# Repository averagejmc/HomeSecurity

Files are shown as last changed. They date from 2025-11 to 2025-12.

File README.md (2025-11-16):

# HomeSecurity 

A small local home security system that:

* receives sensor data via **MQTT**
* shows a real-time dashboard using **Flask + SocketIO**
* logs hourly snapshots to a **SQLite** database
* sends notifications through **Telegram Bot API**

The app runs at **[http://localhost:5000](http://localhost:5000)**.

---

## Requirements

* Python 3.10+
* **uv** (for virtualenv + dependency management)
* Mosquitto (or any MQTT broker at `localhost:1883`)
* Telegram bot token stored in an environment variable
  `TELEGRAM_TOKEN=<your token>`

---

## Installation

### 1. Create and activate the virtual environment

```bash
uv venv
source .venv/bin/activate   # Linux/macOS
```

Windows PowerShell:

```powershell
.\.venv\Scripts\Activate.ps1
```

### 2. Install all dependencies

```bash
uv sync
```

---

## Configure Telegram

For this project, we included the bot token in the code.
However, it is recommended to use environment variables 
instead for API and bot tokens.

Set the bot token as an environment variable:

Linux/macOS:

```bash
export TELEGRAM_TOKEN="your-token"
```

Windows PowerShell:

```powershell
setx TELEGRAM_TOKEN "your-token"
```

---

## Running the App

### 1. Start the MQTT broker

```bash
mosquitto
```

### 2. Run the web server

```bash
uv run webapp.py
```

Then open:

```
http://localhost:5000
```

---

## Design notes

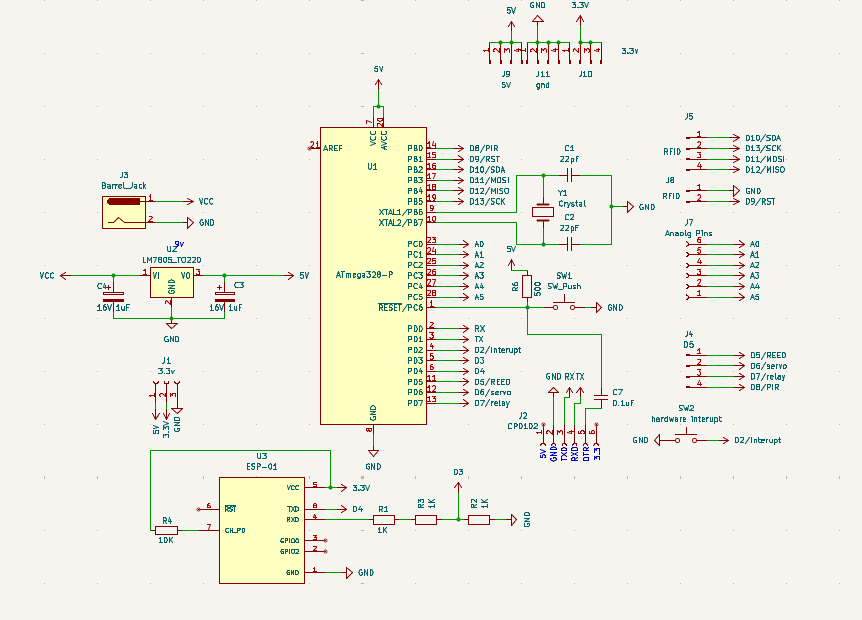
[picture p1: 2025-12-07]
schematic/schematic.png

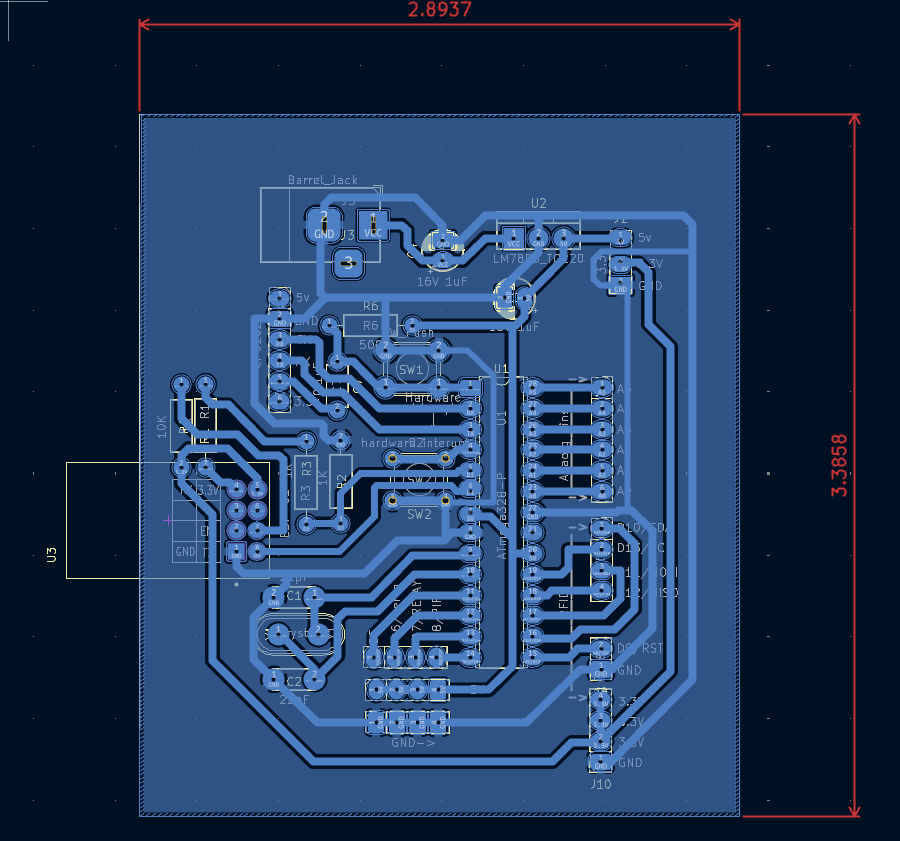
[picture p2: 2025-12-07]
schematic/routing.png

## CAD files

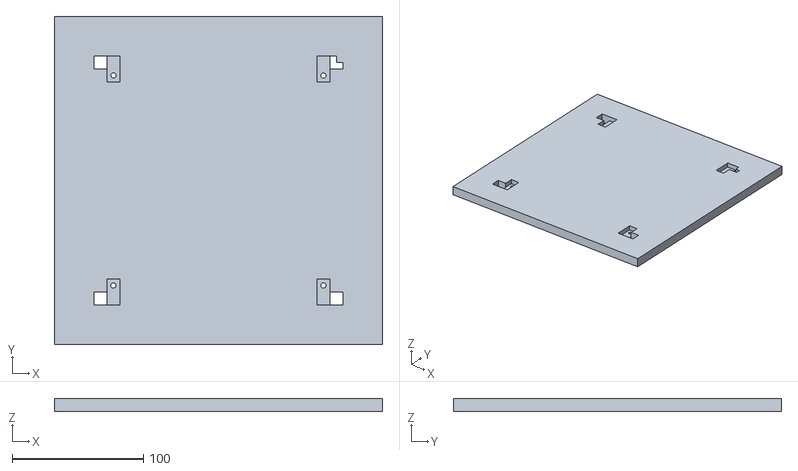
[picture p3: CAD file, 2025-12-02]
3d-models/ground.stl
250.0 x 250.0 x 10.0

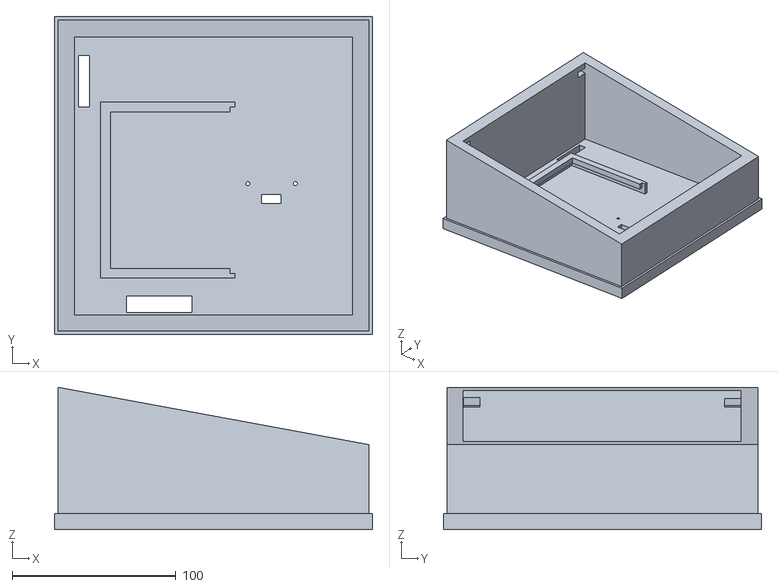
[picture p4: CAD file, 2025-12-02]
3d-models/top.stl
194.3 x 194.3 x 87.1

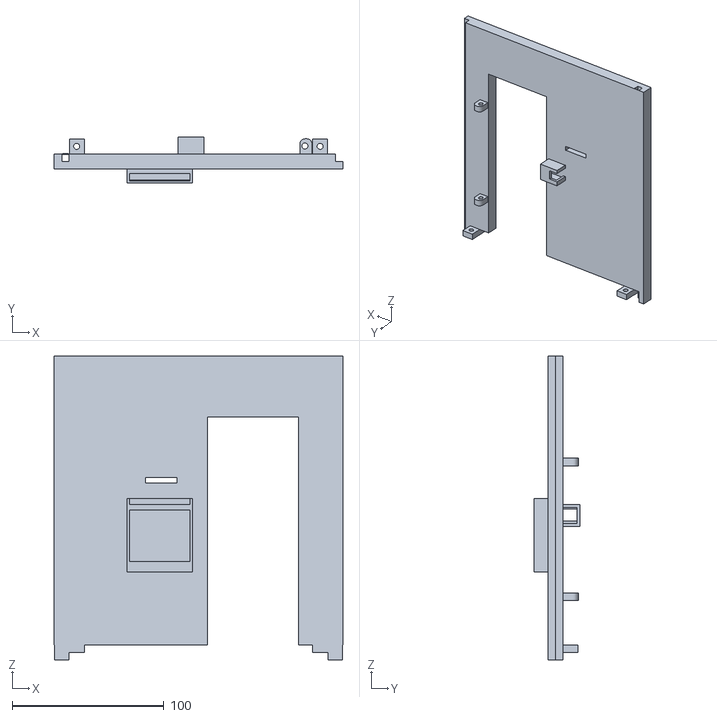
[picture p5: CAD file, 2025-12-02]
3d-models/front.stl
190.0 x 30.0 x 200.0

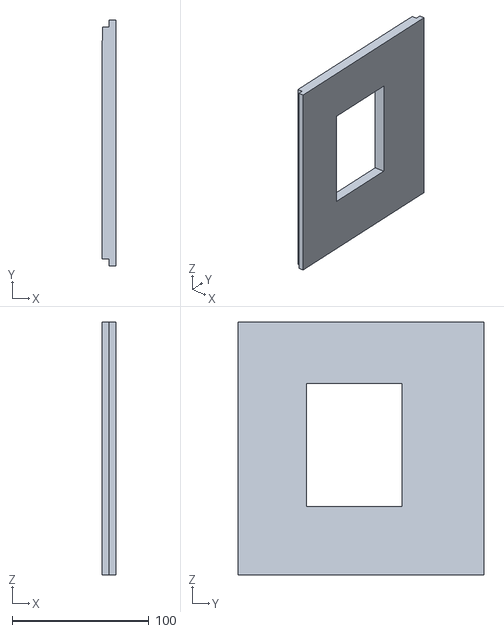
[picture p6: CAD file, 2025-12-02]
3d-models/right.stl
10.0 x 179.9 x 185.0

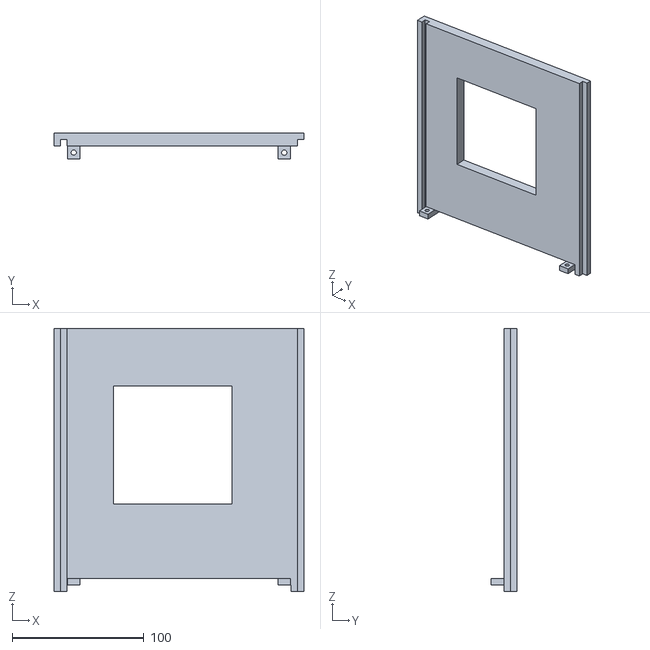
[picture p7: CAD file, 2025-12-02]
3d-models/back.stl
190.0 x 19.9 x 200.0

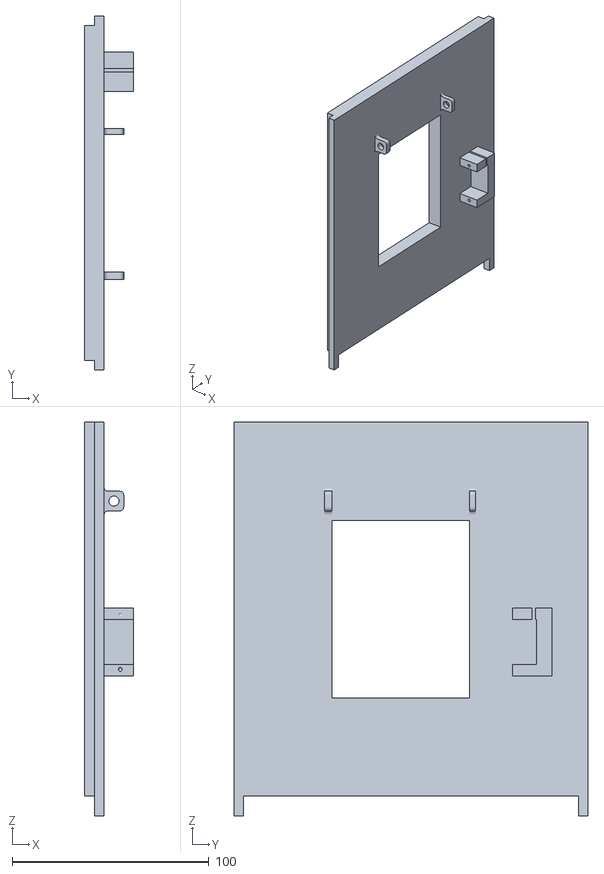
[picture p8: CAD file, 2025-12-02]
3d-models/side.stl
25.0 x 179.8 x 200.0

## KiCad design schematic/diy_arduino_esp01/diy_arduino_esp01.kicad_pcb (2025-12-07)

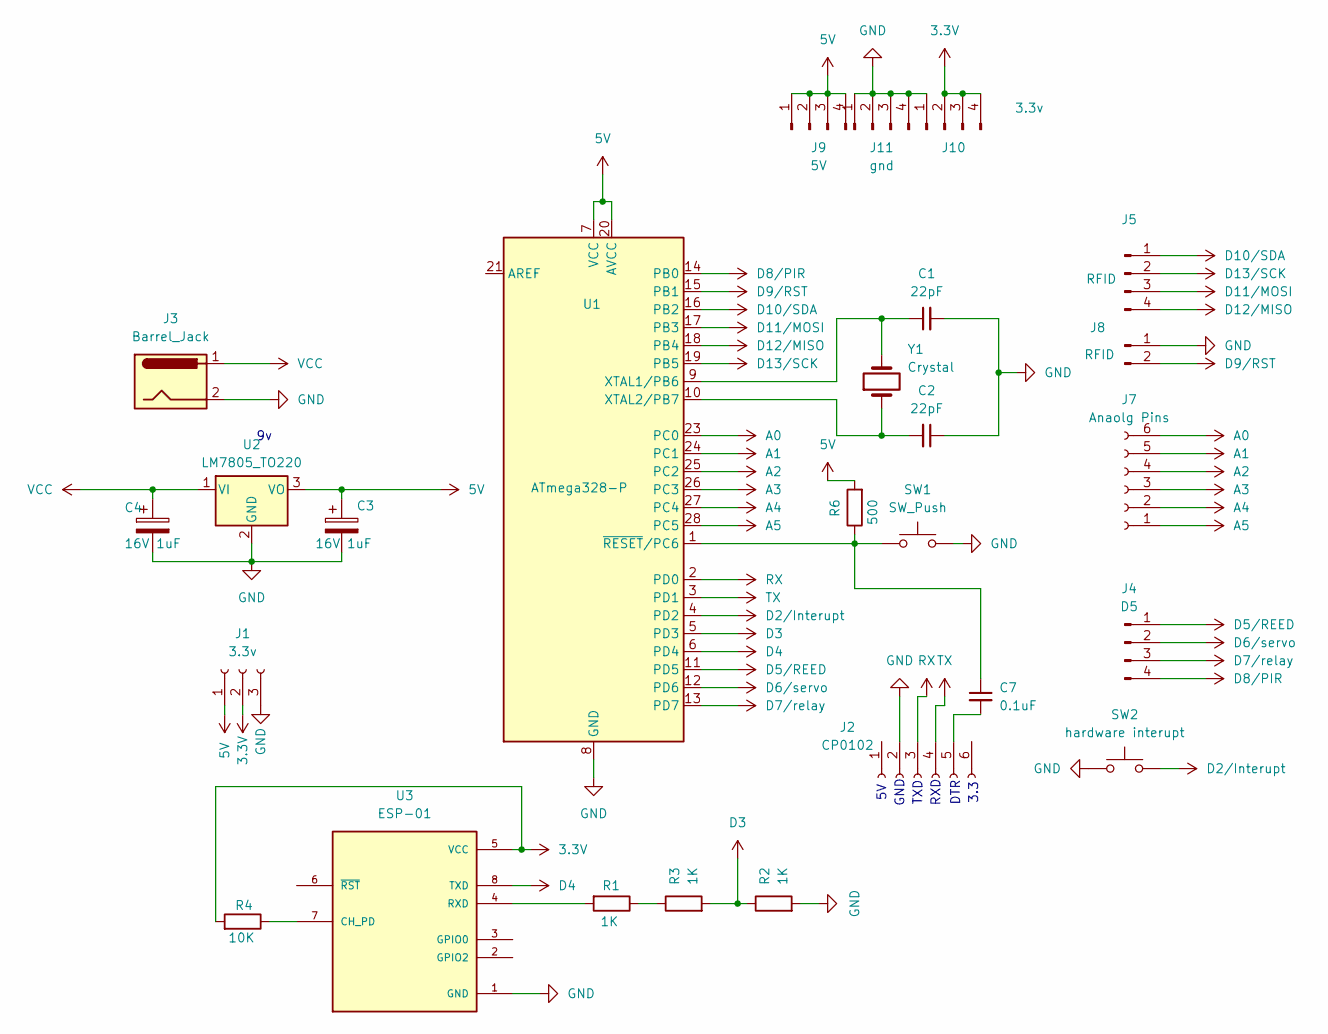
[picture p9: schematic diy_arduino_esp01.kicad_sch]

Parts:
C1, C2: 22pF; C_Disc_D5.0mm_W2.5mm_P5.00mm
C3, C4: 16V 1uF; CP_Radial_D5.0mm_P2.00mm
C7: 0.1uF; C_Disc_D5.0mm_W2.5mm_P5.00mm
J1: 3.3v; PinSocket_1x03_P2.54mm_Vertical
J2: CP0102; PinSocket_1x06_P2.54mm_Vertical
J3: Barrel_Jack; BarrelJack_Horizontal
J4: D5; PinSocket_1x04_P2.54mm_Vertical
J5: RFID; PinSocket_1x04_P2.54mm_Vertical
J7: Anaolg Pins; PinSocket_1x06_P2.54mm_Vertical
J8: RFID; PinSocket_1x02_P2.54mm_Vertical
J9: 5V; PinSocket_1x04_P2.54mm_Vertical
J10: 3.3v; PinSocket_1x04_P2.54mm_Vertical
J11: gnd; PinSocket_1x04_P2.54mm_Vertical
R1, R2, R3: 1K; R_Axial_DIN0207_L6.3mm_D2.5mm_P10.16mm_Horizontal
R4: 10K; R_Axial_DIN0207_L6.3mm_D2.5mm_P10.16mm_Horizontal
R6: 500; R_Axial_DIN0207_L6.3mm_D2.5mm_P10.16mm_Horizontal
SW1: SW_Push; SW_PUSH_6mm
SW2: hardware interupt; SW_PUSH_6mm
U1: ATmega328-P; DIP-28_W7.62mm
U2: LM7805_TO220; TO-220-3_Vertical
U3: ESP-01; MODULE_ESP-01; PARTREV 1.0
Y1: Crystal; Crystal_HC49-U_Vertical

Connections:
3.3V: J1.2, J10.2, J10.3, J10.4, R4.2, U3.5 (VCC)
5V: C3.1, J1.1, J9.1, J9.2, J9.3, J9.4, R6.2, U1.7 (VCC), U1.20 (AVCC), U2.3 (VO)
A0: J7.6, U1.23 (PC0)
A1: J7.5, U1.24 (PC1)
A2: J7.4, U1.25 (PC2)
A3: J7.3, U1.26 (PC3)
A4: J7.2, U1.27 (PC4)
A5: J7.1, U1.28 (PC5)
D2/Interupt: SW2.2, U1.4 (PD2)
D3: R2.1, R3.2, U1.5 (PD3)
D4: U1.6 (PD4), U3.8 (TXD)
D5/REED: J4.1, U1.11 (PD5)
D6/servo: J4.2, U1.12 (PD6)
D7/relay: J4.3, U1.13 (PD7)
D8/PIR: J4.4, U1.14 (PB0)
D9/RST: J8.2, U1.15 (PB1)
D10/SDA: J5.1, U1.16 (PB2)
D11/MOSI: J5.3, U1.17 (PB3)
D12/MISO: J5.4, U1.18 (PB4)
D13/SCK: J5.2, U1.19 (PB5)
GND: C1.2, C2.1, C3.2, C4.2, J1.3, J2.2, J3.2, J8.1, J10.1, J11.1, J11.2, J11.3, J11.4, R2.2, SW1.2, SW2.1, U1.8 (GND), U1.22 (GND), U2.2 (GND), U3.1 (GND)
unnamed: C7.2, J2.5
unnamed: R1.1, R3.1
unnamed: C1.1, U1.9 (XTAL1/PB6), Y1.2
unnamed: C2.2, U1.10 (XTAL2/PB7), Y1.1
unnamed: C7.1, R6.1, SW1.1, U1.1 (~RESET/PC6)
unnamed: R4.1, U3.7 (CH_PD)
unnamed: R1.2, U3.4 (RXD)
RX: J2.3, U1.2 (PD0)
TX: J2.4, U1.3 (PD1)
VCC: C4.1, J3.1, U2.1 (VI)

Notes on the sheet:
DTR
TXD
GND
RXD
3.3

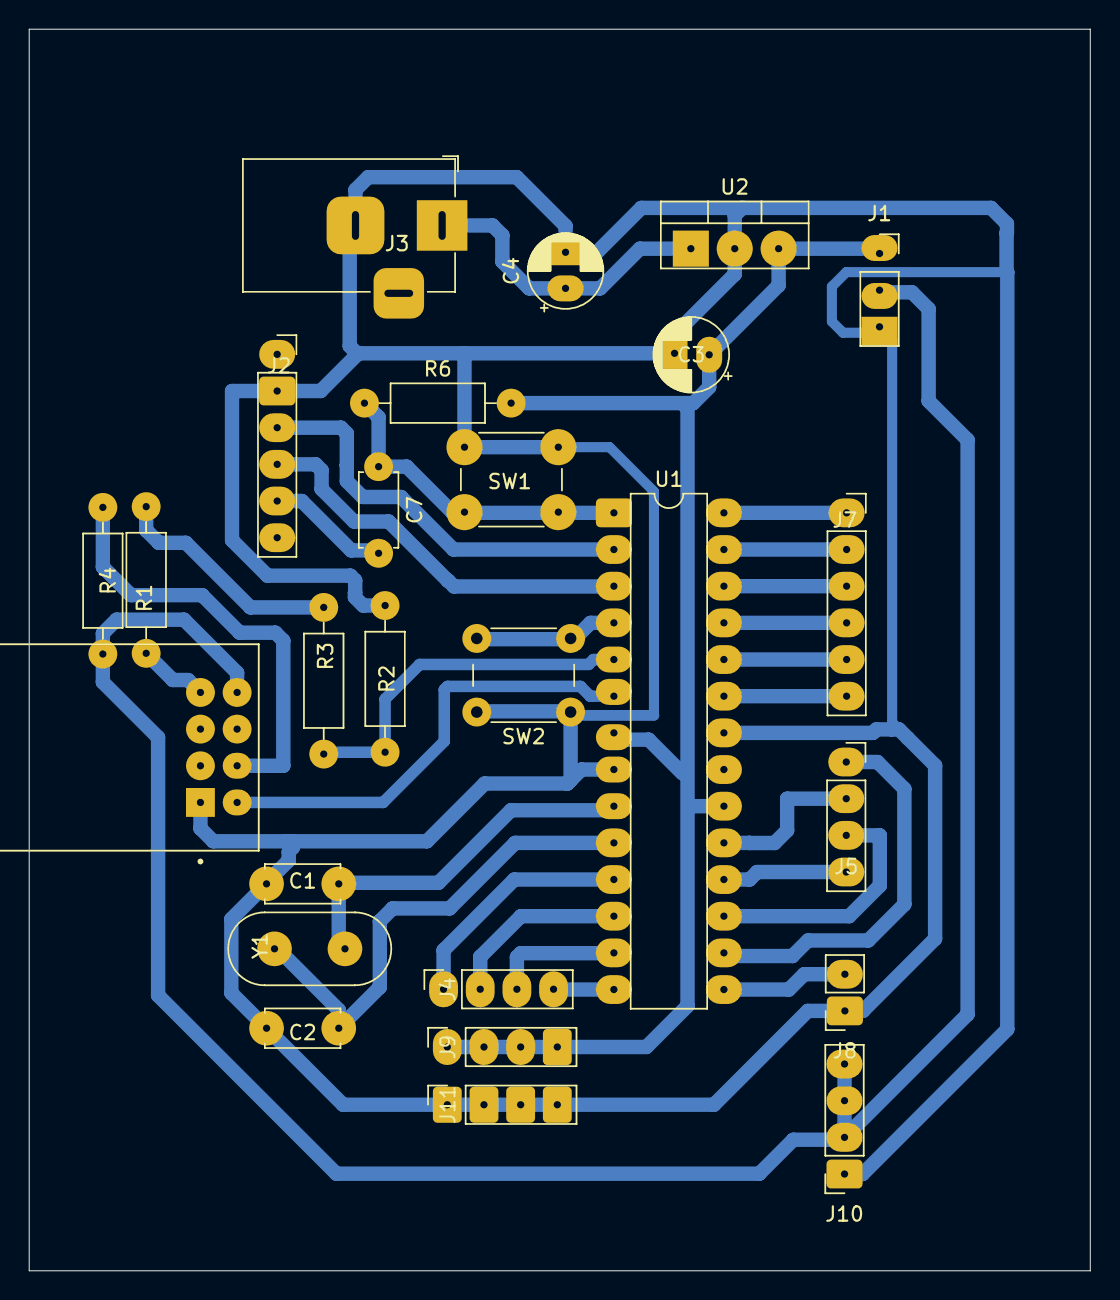
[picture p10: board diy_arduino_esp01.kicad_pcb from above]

Board: 2 copper layers, 73.5 x 86.0 mm, 26 parts (0 on the bottom side), 31 nets.

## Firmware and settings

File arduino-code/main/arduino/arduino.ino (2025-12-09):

#include <SPI.h>
#include <MFRC522.h>
#include <SoftwareSerial.h>
#include <avr/sleep.h>
#include <avr/power.h>
#include <Servo.h>

#include "DoorSensor.h"
#include "MotionSensor.h"
#include "RFIDSensor.h"

const int ARDUINO_RX_PIN = 4;
const int ARDUINO_TX_PIN = 3;
const int RST_PIN = 9;   // Reset pin for RFID sensor
const int SS_PIN = 10;   // SDA/SS pin for RFID sensotr
const int motionPin = 8;  // PIR sensor
const int doorPin  = 5;  // Magnetic door sensor
const int servoPin = 6;
const int solenoidPin = 7;
const int switchPin = 2;
//const int ledPin = 5;

const int SERVO_LEFT = 70;
const int SERVO_STOP = 90;
const int SERVO_RIGHT = 110;
int currentServoSpeed = SERVO_STOP;

SoftwareSerial espSerial(ARDUINO_RX_PIN, ARDUINO_TX_PIN);
DoorSensor doorSensor(doorPin);
MotionSensor motionSensor(motionPin);
RFIDSensor rfidSensor(SS_PIN, RST_PIN);
Servo myServo;

unsigned long lastHeartbeat = 0;
const unsigned long heartbeatInterval = 30000;

unsigned long lastSendTime = 0;
const unsigned long sendInterval = 5000;

const unsigned long SOLENOID_DURATION = 3000; 
const unsigned long SERVO_DURATION = 2500;
const unsigned long HOLD_DURATION = 15000;

unsigned long sequenceStartTime = 0;
bool isSequenceActive = false;

//unsigned long lastBlink = 0;
//const unsigned long blinkInterval = 1000;
//bool ledState = LOW;

String lastUid = "";

enum SystemMode { AUTO = 0, MAINTENANCE, SLEEP, MODE_COUNT };
volatile SystemMode currentMode = AUTO;

void switchMode() {
  static unsigned long lastInterruptTime = 0;
  unsigned long interruptTime = millis();
  if (currentMode == SLEEP || interruptTime - lastInterruptTime > 200) {
    currentMode = static_cast<SystemMode>((currentMode + 1) % MODE_COUNT);
    lastInterruptTime = interruptTime;
  }
}

void sendDataToESP(String uid) {
  myServo.detach();
  
  espSerial.print(String(currentMode));
  espSerial.print(F(","));
  espSerial.print(motionSensor.getMessage());
  espSerial.print(F(","));
  espSerial.print(doorSensor.getMessage());
  espSerial.print(F(","));
  if (uid == "") {
    espSerial.println("No RFID"); 
  } else {
    espSerial.println(uid);
  }

  delay(10);

  myServo.attach(servoPin);
  myServo.write(currentServoSpeed);

  Serial.println(F("ARDUINO: Sent data to ESP"));
}

void setup() {
  Serial.begin(115200);
  espSerial.begin(9600);

  pinMode(switchPin, INPUT_PULLUP);
  attachInterrupt(digitalPinToInterrupt(switchPin), switchMode, FALLING);

//  pinMode(ledPin, OUTPUT);
//  digitalWrite(ledPin, LOW);

  doorSensor.begin();
  motionSensor.begin();
  rfidSensor.begin();

  myServo.attach(servoPin);
  myServo.write(SERVO_STOP);

  digitalWrite(solenoidPin, HIGH);
  pinMode(solenoidPin, OUTPUT);

  Serial.println(F("ARDUINO: System Ready"));

  power_adc_disable();
  power_twi_disable();
  ACSR |= (1 << ACD);
  power_timer2_disable();
}

void checkSequence() {
  if (!isSequenceActive) return; 

  unsigned long elapsed = millis() - sequenceStartTime;
  
  if (elapsed < SOLENOID_DURATION) {
    digitalWrite(solenoidPin, LOW); 
  } else {
    digitalWrite(solenoidPin, HIGH); 
  }
  
  if (elapsed < SERVO_DURATION) {
    currentServoSpeed = SERVO_RIGHT;
    myServo.write(SERVO_RIGHT);
  } 
  else if (elapsed < (SERVO_DURATION + HOLD_DURATION)) {
    currentServoSpeed = SERVO_STOP;
    myServo.write(SERVO_STOP); 
  } 
  else if (elapsed < (SERVO_DURATION + HOLD_DURATION + SERVO_DURATION)) {
    currentServoSpeed = SERVO_LEFT;
    myServo.write(SERVO_LEFT);  
  } 
  else {
    currentServoSpeed = SERVO_STOP;
    myServo.write(SERVO_STOP); 
    isSequenceActive = false; 
    Serial.println(F("Sequence Complete (Closed)."));
  }
}

void loop() {
  motionSensor.update();
  doorSensor.update();
  
  String rawUid = rfidSensor.read();
  String currentUid = "";

  if (rawUid != "") {
    currentUid = rawUid;
  }

  checkSequence();

  bool eventDetected = false;

  if (motionSensor.hasStateChanged()) {
    if (!isSequenceActive) { 
        eventDetected = true;
        Serial.println(F(">>> MOTION DETECTED! <<<")); 
    }
  }
  if (doorSensor.hasStateChanged()) eventDetected = true;
  if (currentUid != lastUid) {
    if (currentUid != "") {
      eventDetected = true;
      if (!isSequenceActive) {
        isSequenceActive = true;
        sequenceStartTime = millis();
      }
    }
    lastUid = currentUid;
  }
  
  switch (currentMode) {
    case AUTO:
//     digitalWrite(ledPin, LOW);
     if (eventDetected || (millis() - lastHeartbeat >= heartbeatInterval)) {
        lastHeartbeat = millis();
        if (currentUid != "") {
            sendDataToESP(currentUid);
        } else {
            sendDataToESP("");
        }
      }
      break;

    case MAINTENANCE:
//      if (millis() - lastBlink >= blinkInterval) {
//        lastBlink = millis();
//        ledState = !ledState;
//        digitalWrite(ledPin, ledState);
//      }

      if (millis() - lastSendTime >= sendInterval) {
        lastSendTime = millis();
        sendDataToESP(lastUid);
      }
      break;

    case SLEEP:
//      digitalWrite(ledPin, HIGH); 
      sendDataToESP(lastUid);
      delay(100);
      
      set_sleep_mode(SLEEP_MODE_PWR_DOWN);
      sleep_enable();
      sleep_cpu();
      sleep_disable(); 
      break;

    default:
      break;
  }
}

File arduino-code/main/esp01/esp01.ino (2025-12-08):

#include <Arduino.h>
#include <ESP8266WiFi.h>

#include "MqttHandler.h"  

const char* SSID = "Forger_Hideout_IoT";
const char* PASSWORD = "AnyaLoidYor";
const char* MQTT_SERVER = "192.168.68.55";

MQTTClientHandler mqtt(SSID, PASSWORD, MQTT_SERVER);

String incoming = "";

void setup() {
  Serial.begin(9600);
  mqtt.begin();

  Serial.println("ESP01: ESP01 MQTT BRIDGE READY");
}

void loop() {
  mqtt.loop();

  while (Serial.available()) {
    char c = Serial.read();
    if (c == '\n') {
      processLine(incoming);
      incoming = "";
    } else {
      incoming += c;
    }
  }
}

void processLine(String line) {
  line.trim();
  if (line.length() == 0) return;

  // Split CSV
  int idx1 = line.indexOf(',');
  int idx2 = line.indexOf(',', idx1 + 1);
  int idx3 = line.indexOf(',', idx2 + 1);

  if (idx1 < 0 || idx2 < 0 || idx3 < 0) return;

  String currentMode  = line.substring(0, idx1);
  String motion = line.substring(idx1 + 1, idx2);
  String door   = line.substring(idx2 + 1, idx3);
  String rfid   = line.substring(idx3 + 1);

  // Publish
  mqtt.publish("home/mode", currentMode.c_str());
  mqtt.publish("home/motion", motion.c_str());
  mqtt.publish("home/door", door.c_str());

  if (rfid.length() > 0)
    mqtt.publish("home/rfid", rfid.c_str());

  Serial.println("Published: " + line);
}

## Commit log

2025-11-08 Added Schematic for DIY Arduino with esp-01s
    [diy_arduino_esp01.kicad_pcb, diy_arduino_esp01.kicad_sch]
2025-11-08 Add schematic and routing images
2025-11-28 added arduino code
2025-11-28 added arduino code for real this time
2025-11-28 trying to make header on the arduino code
2025-11-29 improved frontend
    [diy_arduino_esp01.kicad_pcb, diy_arduino_esp01.kicad_sch]
2025-11-30 code for arduino and esp01
2025-11-30 separated logic for arduino and esp01
2025-11-30 Added mode switching and Hardware Interrupt
2025-12-02 Added 3d models
    [back.stl, front.stl, ground.stl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]
2025-12-02 updated schematic
    [diy_arduino_esp01.kicad_pcb, freerouting.dsn, temp-freerouting.dsn]
2025-12-07 final schematic
    [diy_arduino_esp01.kicad_pcb, diy_arduino_esp01.kicad_sch]
2025-12-08 update arduino code and backend one last time
